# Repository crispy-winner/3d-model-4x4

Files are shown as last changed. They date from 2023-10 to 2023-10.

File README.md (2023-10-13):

# Macro Pad 4x4

В данном репозитории разведена печатная плата на основе микроконтроллера
[STM32F103CBT6](https://aliexpress.ru/popular/stm32f103cbt6.html) с USB Type-C.

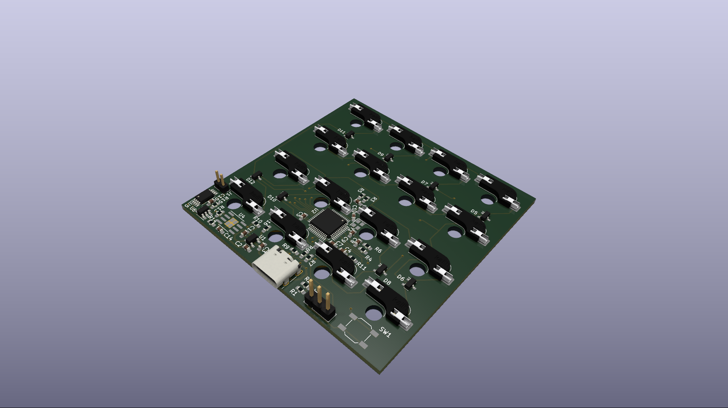
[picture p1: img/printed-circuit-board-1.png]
Скрин №1

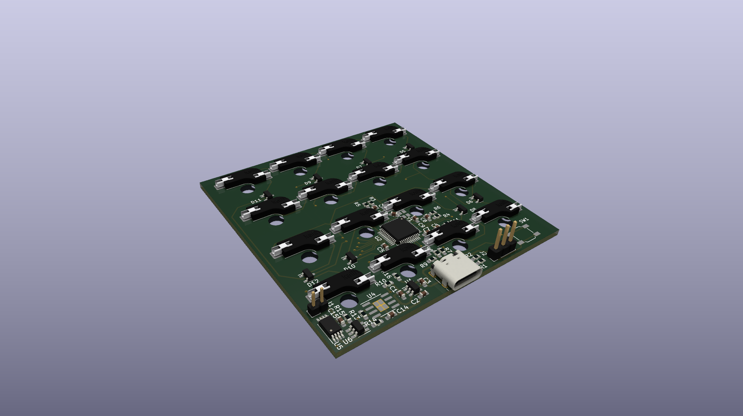
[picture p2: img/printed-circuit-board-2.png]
Скрин №2

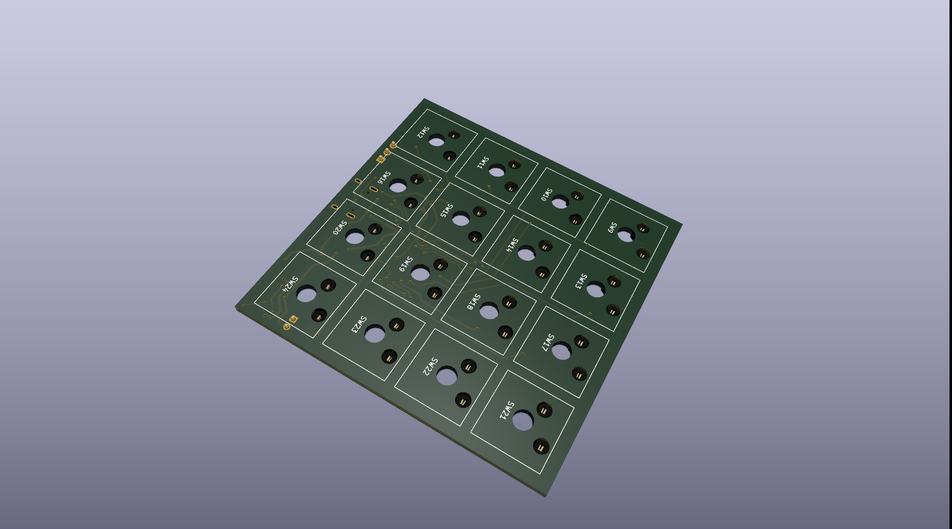
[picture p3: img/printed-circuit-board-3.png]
Скрин №3


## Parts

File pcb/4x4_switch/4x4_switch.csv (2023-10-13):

# | Reference | Qty | Value | Footprint | DNP
1 | C1, C3 | 2 | 1mkF | Capacitor_SMD:C_0603_1608Metric_Pad1.08x0.95mm_HandSolder
2 | C2 | 1 | byp10nF | Capacitor_SMD:C_0603_1608Metric_Pad1.08x0.95mm_HandSolder
3 | C4 | 1 | 10mkF | Capacitor_SMD:C_0603_1608Metric_Pad1.08x0.95mm_HandSolder
4 | C5, C6, C7, C8, C14, C15 | 6 | 100nF | Capacitor_SMD:C_0603_1608Metric_Pad1.08x0.95mm_HandSolder
5 | C9, C10 | 2 | 20pF | Capacitor_SMD:C_0603_1608Metric_Pad1.08x0.95mm_HandSolder
6 | D5, D6, D7, D8, D9, D10, D11, D12 | 8 | BAT54C | Package_TO_SOT_SMD:SOT-23
7 | J1 | 1 | Conn_01x02 | Connector_PinHeader_2.00mm:PinHeader_1x02_P2.00mm_Vertical
8 | J2 | 1 | Conn_01x03 | Connector_PinHeader_2.54mm:PinHeader_1x03_P2.54mm_Vertical
9 | P1 | 1 | USB_C_Plug_USB2.0 | Connector_USB:USB_C_Receptacle_HRO_TYPE-C-31-M-12
10 | R1, R2 | 2 | 5.1k | Resistor_SMD:R_0603_1608Metric_Pad0.98x0.95mm_HandSolder
11 | R3, R4 | 2 | 100k | Resistor_SMD:R_0603_1608Metric_Pad0.98x0.95mm_HandSolder
12 | R5, R6, R11 | 3 | 10k | Resistor_SMD:R_0603_1608Metric_Pad0.98x0.95mm_HandSolder
13 | R7, R8 | 2 | 20R | Resistor_SMD:R_0603_1608Metric_Pad0.98x0.95mm_HandSolder
14 | R9, R14 | 2 | 1k | Resistor_SMD:R_0603_1608Metric_Pad0.98x0.95mm_HandSolder
15 | R10, R16 | 2 | 0 | Resistor_SMD:R_0603_1608Metric_Pad0.98x0.95mm_HandSolder
16 | R13 | 1 | 1.2k | Resistor_SMD:R_0603_1608Metric_Pad0.98x0.95mm_HandSolder
17 | R15 | 1 | 100 | Resistor_SMD:R_0603_1608Metric_Pad0.98x0.95mm_HandSolder
18 | SW1 | 1 | SW_DIP_x01 | Button_Switch_SMD:SW_SPST_SKQG_WithoutStem
19 | SW9, SW10, SW11, SW12, SW13, SW14, SW15, SW16, SW17, SW18, SW19, SW20, SW21, SW22, SW23, SW24 | 16 | SW_DIP_x01 | libs:SW_Hotswap_Kailh_MX_1.00u
20 | U1 | 1 | LD3985M33R_SOT23 | Package_TO_SOT_SMD:SOT-23-5
21 | U2 | 1 | STM32F103C8Tx | Package_QFP:LQFP-48_7x7mm_P0.5mm
22 | U4 | 1 | TP4056 | Package_SO:SOIC-8-1EP_3.9x4.9mm_P1.27mm_EP2.29x3mm
23 | U5 | 1 | FS8205A | Package_SO:TSSOP-8_4.4x3mm_P0.65mm
24 | U6 | 1 | DW01 | Package_TO_SOT_SMD:SOT-23-6_Handsoldering
25 | Y1 | 1 | Crystal | Crystal:Crystal_SMD_2520-4Pin_2.5x2.0mm

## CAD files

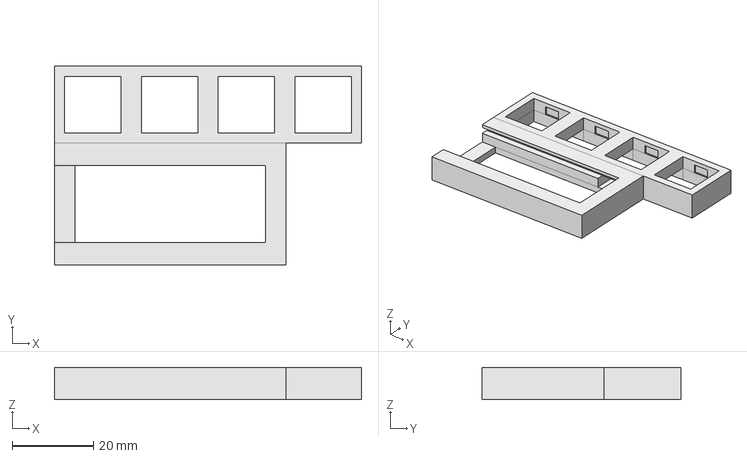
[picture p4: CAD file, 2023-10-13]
case/4x1_test_case.FCStd
75.6 x 48.9 x 8.00 mm

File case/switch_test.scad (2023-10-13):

module socket(l=13.9, wall=2, height=4)
{
        difference()
        {
                difference(){
                        cube([l+wall*2, l+wall*2, height]);
                        translate([wall, wall, -1])
                                cube([l, l, height+2]);
                }
                translate([wall-0.5, (l+wall*2-5)/2, -(1.3)])
                        cube([l+1, 5, height]);
        }
}


module keypad_matrix(count_x=6, count_y=6, socket=[13.9, 2.5, 2], wall=2, height=8)
{
        transp=(socket[0]+2*socket[1]);
        for(x=[0:count_x-1])
        {

                for(y=[0:count_y-1])
                {
                        translate([x*transp, y*transp, 0])
                                socket(socket[0],socket[1],socket[2]);
                }
        }
        translate([0,0,-(height-socket[2])])
        difference()
        {
        translate([-socket[1],-socket[1],0])
        cube([(count_x)*transp+wall*2, (count_y)*transp+wall*2, height]);
        translate([0,0,-0.1])
        cube([(count_x)*transp, (count_y)*transp, height+0.2]);
        }


}

keypad_matrix(count_x=6, count_y=5);

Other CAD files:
case/4x1_test_case-Тело.stl

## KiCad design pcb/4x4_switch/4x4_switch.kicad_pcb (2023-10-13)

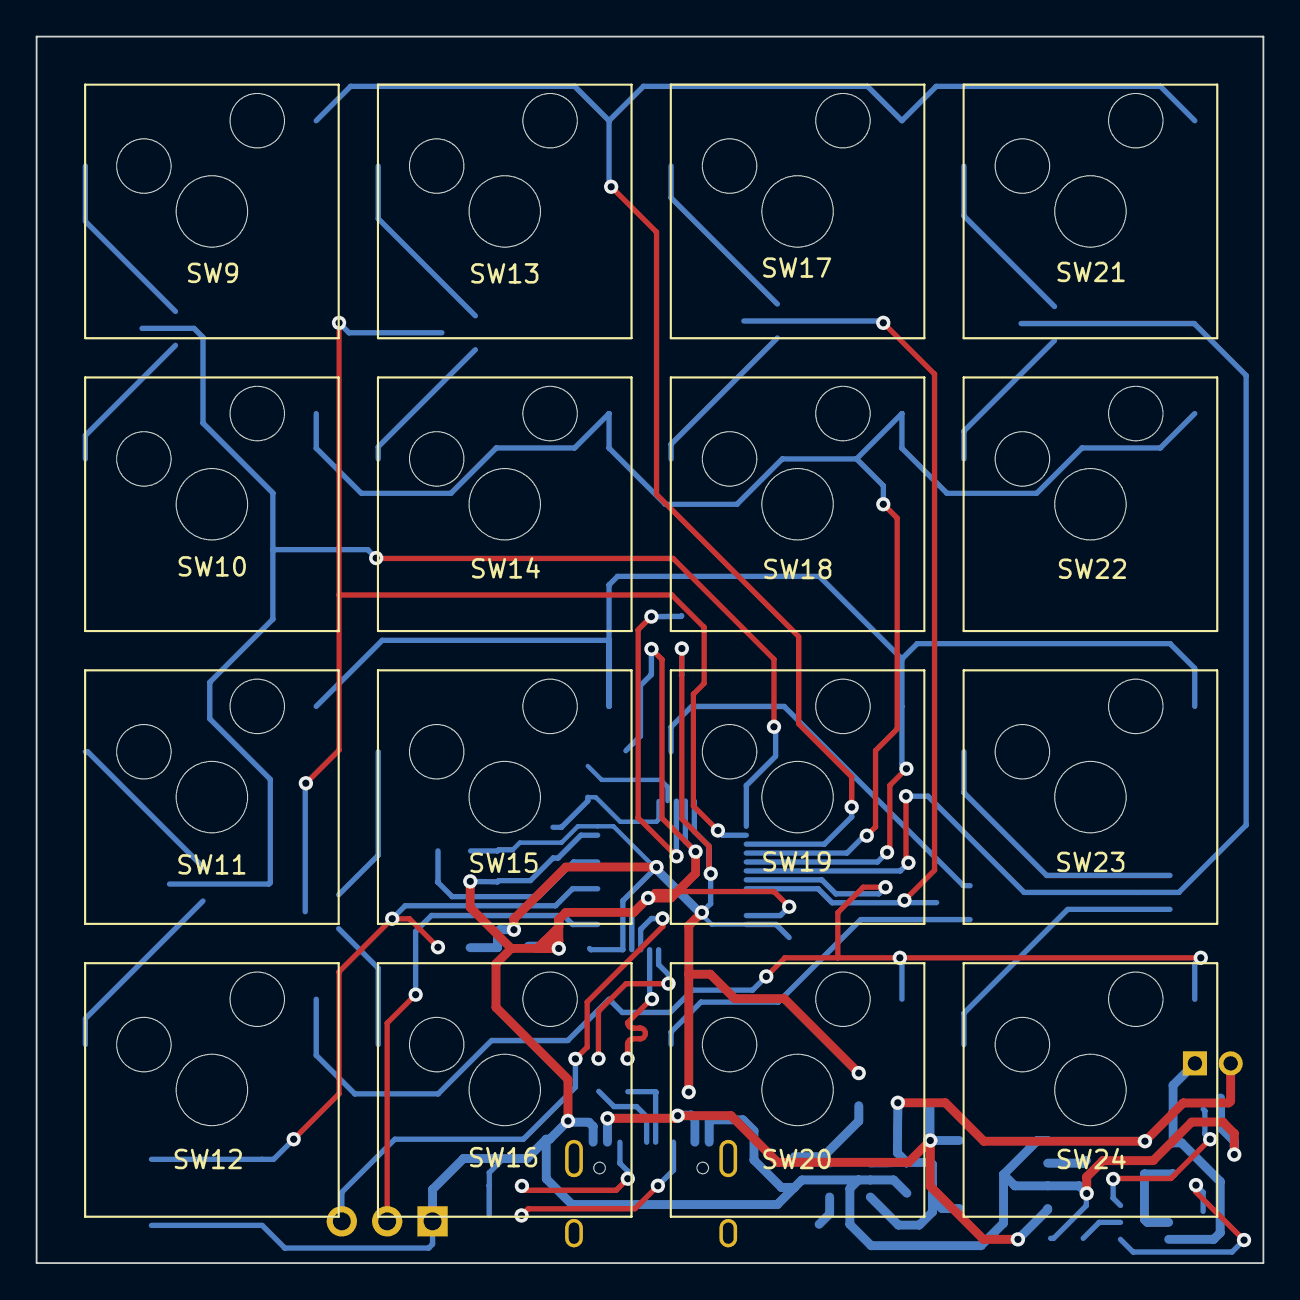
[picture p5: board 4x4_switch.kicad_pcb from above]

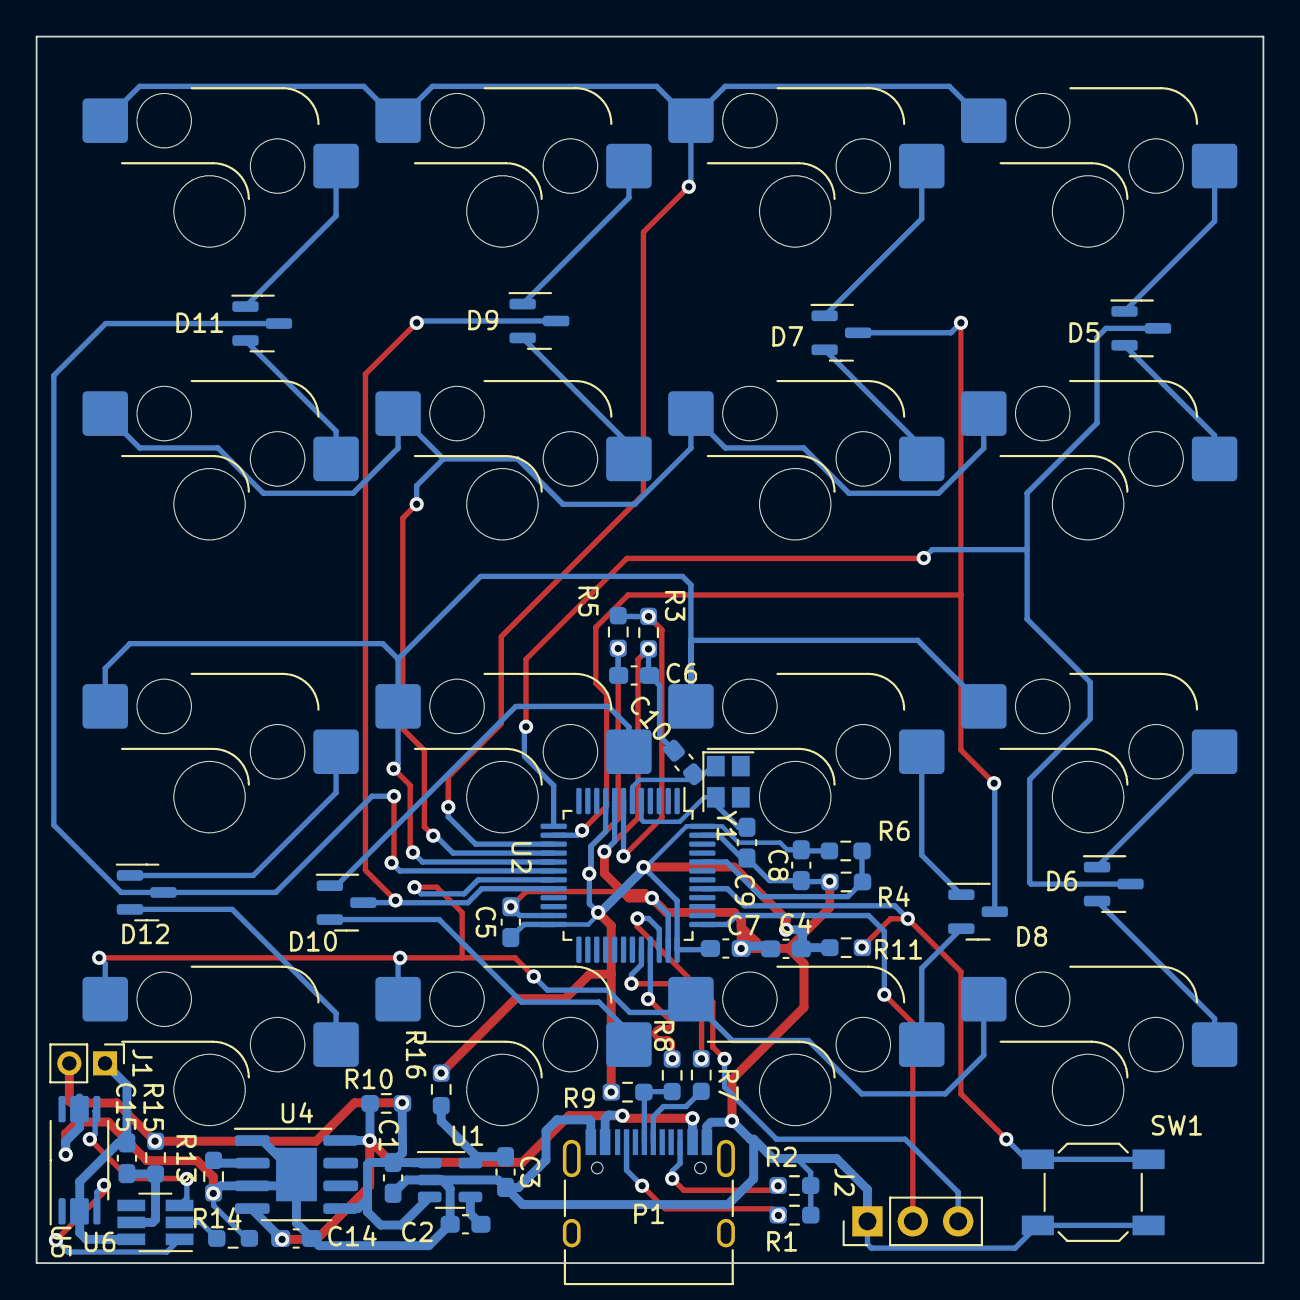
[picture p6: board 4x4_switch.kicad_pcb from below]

Board: 2 copper layers, 68.7 x 68.7 mm, 61 parts (45 on the bottom side), 49 nets.

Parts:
C1, C3: 1mkF; C_0603_1608Metric_Pad1.08x0.95mm_HandSolder
C2: byp10nF; C_0603_1608Metric_Pad1.08x0.95mm_HandSolder
C4: 10mkF; C_0603_1608Metric_Pad1.08x0.95mm_HandSolder
C5, C6, C7, C8, C14, C15: 100nF; C_0603_1608Metric_Pad1.08x0.95mm_HandSolder
C9, C10: 20pF; C_0603_1608Metric_Pad1.08x0.95mm_HandSolder
D5, D6, D7, D8, D9, D10, D11, D12: BAT54C; SOT-23
J1: Conn_01x02; PinHeader_1x02_P2.00mm_Vertical
J2: Conn_01x03; PinHeader_1x03_P2.54mm_Vertical
P1: USB_C_Plug_USB2.0; USB_C_Receptacle_HRO_TYPE-C-31-M-12
R1, R2: 5.1k; R_0603_1608Metric_Pad0.98x0.95mm_HandSolder
R3, R4: 100k; R_0603_1608Metric_Pad0.98x0.95mm_HandSolder
R5, R6, R11: 10k; R_0603_1608Metric_Pad0.98x0.95mm_HandSolder
R7, R8: 20R; R_0603_1608Metric_Pad0.98x0.95mm_HandSolder
R9, R14: 1k; R_0603_1608Metric_Pad0.98x0.95mm_HandSolder
R10, R16: 0; R_0603_1608Metric_Pad0.98x0.95mm_HandSolder
R13: 1.2k; R_0603_1608Metric_Pad0.98x0.95mm_HandSolder
R15: 100; R_0603_1608Metric_Pad0.98x0.95mm_HandSolder
SW1: SW_DIP_x01; SW_SPST_SKQG_WithoutStem
SW9, SW10, SW11, SW12, SW13, SW14, SW15, SW16, SW17, SW18, SW19, SW20, SW21, SW22, SW23, SW24: SW_DIP_x01; SW_Hotswap_Kailh_MX_1.00u
U1: LD3985M33R_SOT23; SOT-23-5
U2: STM32F103C8Tx; LQFP-48_7x7mm_P0.5mm
U4: TP4056; SOIC-8-1EP_3.9x4.9mm_P1.27mm_EP2.29x3mm
U5: FS8205A; TSSOP-8_4.4x3mm_P0.65mm
U6: DW01; SOT-23-6_Handsoldering
Y1: Crystal; Crystal_SMD_2520-4Pin_2.5x2.0mm

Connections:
+3.3V: C4.1, C5.1, C6.1, C7.1, C8.1, R5.1, R6.1, R9.2, R11.1, R16.2, U2.9 (VDDA), U2.24 (VDD), U2.36 (VDD), U2.48 (VDD)
+5V: C14.1, P1.A4 (VBUS), P1.A9 (VBUS), P1.B4 (VBUS), P1.B9 (VBUS), R10.2, U4.4 (VCC), U4.8 (CE)
+BATT: C1.1, J1.2, R10.1, R15.1, U1.1 (VIN), U1.3 (INH), U4.5 (BAT)
-BATT: C15.2, J1.1, U5.2 (Source_1), U5.3 (Source_1), U6.6 (GND)
BOOT0: R4.2, R6.2, U2.44 (BOOT0)
GND: C1.2, C2.2, C3.2, C4.2, C5.2, C6.2, C7.2, C8.2, C9.2, C10.2, C14.2, J2.1, P1.A1 (GND), P1.A12 (GND), P1.B1 (GND), P1.B12 (GND), R1.1, R2.1, R3.1, R4.1, R13.1, R14.1, SW1.1, U1.2 (GND), U2.8 (VSSA), U2.23 (VSS), U2.35 (VSS), U2.47 (VSS), U4.1 (TEMP), U4.3 (GND), U4.9 (PP), U5.6 (Source_2), U5.7 (Source_2)
unnamed: D5.1, SW9.1
unnamed: D5.2, SW10.1
unnamed: D6.1, SW11.1
unnamed: D6.2, SW12.1
unnamed: D7.1, SW13.1
unnamed: D7.2, SW14.1
unnamed: D8.1, SW15.1
unnamed: D8.2, SW16.1
unnamed: D9.1, SW17.1
unnamed: D9.2, SW18.1
unnamed: D10.1, SW19.1
unnamed: D10.2, SW20.1
unnamed: D11.1, SW21.1
unnamed: D11.2, SW22.1
unnamed: D12.1, SW23.1
unnamed: D12.2, SW24.1
unnamed: P1.A5 (CC), R1.2
unnamed: P1.A6 (D+), R8.2, R9.1
unnamed: P1.A7 (D-), R7.2
unnamed: P1.B5 (VCONN), R2.2
unnamed: C2.1, U1.4 (BYP)
unnamed: C3.1, R16.1, U1.5 (VOUT)
unnamed: R11.2, SW1.2, U2.41 (PB5)
unnamed: R13.2, U4.2 (PROG)
unnamed: U5.4 (Gate_1), U6.1 (OD)
unnamed: U5.5 (Gate_2), U6.3 (OC)
unnamed: R14.2, U6.2 (CS)
unnamed: C15.1, R15.2, U6.5 (VCC)
RESET: R3.2, R5.2, U2.7 (NRST)
SWCLK: J2.2, U2.37 (PA14)
SWDIO: J2.3, U2.34 (PA13)
USB_D+: R8.1, U2.33 (PA12)
USB_D-: R7.1, U2.32 (PA11)
col_1: D5.3, D6.3, U2.13 (PA3)
col_2: D7.3, D8.3, U2.14 (PA4)
col_3: D9.3, D10.3, U2.20 (PB2)
col_4: D11.3, D12.3, U2.18 (PB0)
osc1: C9.1, U2.5 (PD0), Y1.2
osc2: C10.1, U2.6 (PD1), Y1.1
row_1: SW9.2, SW13.2, SW17.2, SW21.2, U2.15 (PA5)
row_2: SW10.2, SW14.2, SW18.2, SW22.2, U2.16 (PA6)
row_3: SW11.2, SW15.2, SW19.2, SW23.2, U2.17 (PA7)
row_4: SW12.2, SW16.2, SW20.2, SW24.2, U2.19 (PB1)
